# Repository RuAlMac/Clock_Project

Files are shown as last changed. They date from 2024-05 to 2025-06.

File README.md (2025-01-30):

<h1>RADM Clock Project</h1>

<p>Hello and welcome to the repository for my clock project! This project was inspired by redditor <a href="https://www.reddit.com/user/joshr120/"> u/joshr120</a>. See his post <a href="https://www.reddit.com/r/ArduinoProjects/comments/1caxkm6/my_clock_made_of_24_clocks_and_48_stepper_motors/">here</a>.</p>
<p>The various parts of this project are listed below.</p>

<p><h3>Custom Printed Circuit Boards (PCBs)</h3>
<ul>
  <li><strong>Individual Clock Board:</strong> 24 used, one for each analog clock (2 steppers, one for each hand)</li>
  <li><strong>Clock Cluster Board:</strong> 4 used, one for each segment (6 clocks)>/li>
  <li><strong>Power Routing Board:</strong> 1 used, includes fuses for distributing power safely to all steppers and microcontrollers</li>
  <li><strong>Small Parts Board:</strong> 50 used, two per clock for hall effect sensors for steppers, more for miscellaneous components</li>
</ul>
</p>

<p><h3>Code</h3>
<ul>
  <li>Individual Clock Board Code</li>
  <li>Main System Controller Code</li>
  <li>Regular Clock Cluster Board Code</li>
</ul>
</p>

<p><h3>3D-Printed Parts</h3>
<a href="https://cad.onshape.com/documents/1d75280899b064ab337b95c3/w/e03d29798e6817c57c79d56d/e/417be124aab67788fec76c11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">This Onshape workspace</a> contains all the parts I designed for this project, and also includes the assembly models for the entire project.
</p>

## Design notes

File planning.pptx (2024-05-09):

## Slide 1

Components for clock cluster board:
- IR Receiver (not all will have)
- RTC module (not all will have)
- 7-seg display
- 8 each GND, 5V, SDA, SCL
Pins on clock cluster board:
- Pins 2-4: Shift Register control (for 7seg display)
- Pin 5: DP control (for 7seg display)
- Pin 6: IR Receiver module data pin
- [RTC module uses I2C communication w/ Arduino]

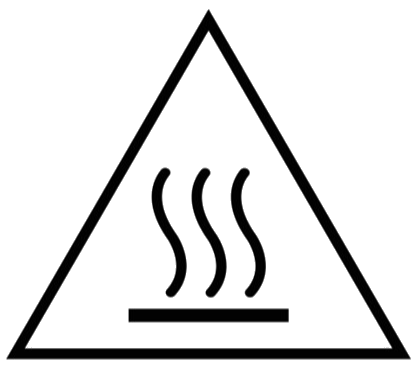
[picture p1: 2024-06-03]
PCBs/Power Routing Board/hot surface symbol.png

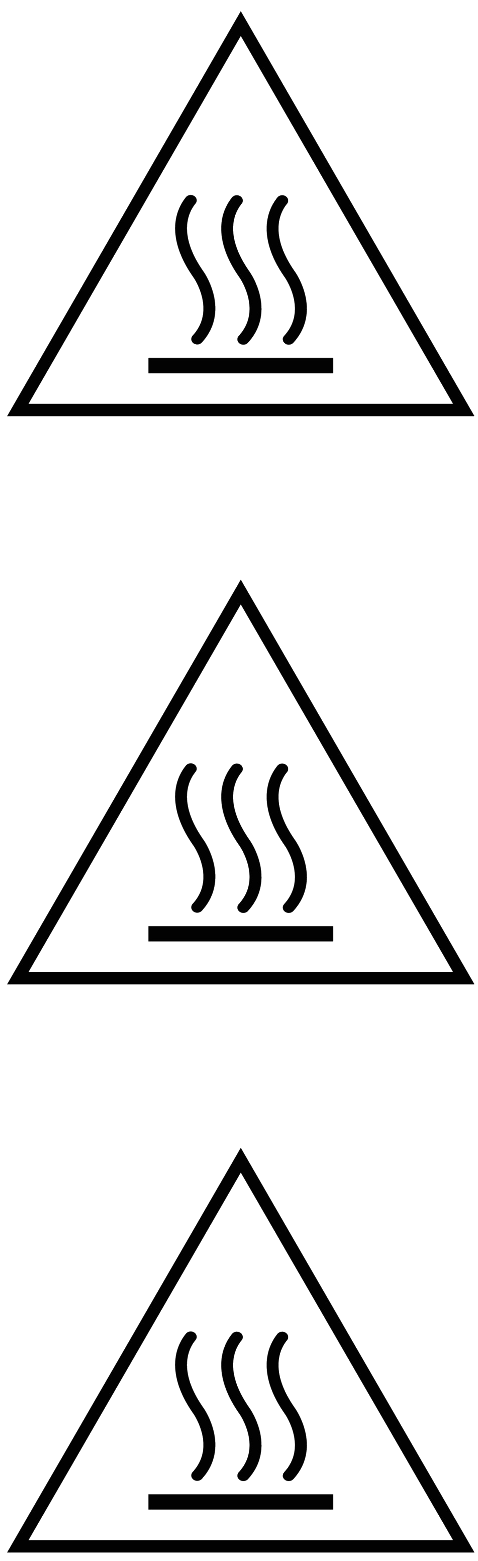
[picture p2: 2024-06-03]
PCBs/Power Routing Board/hot surface symbol x3.png

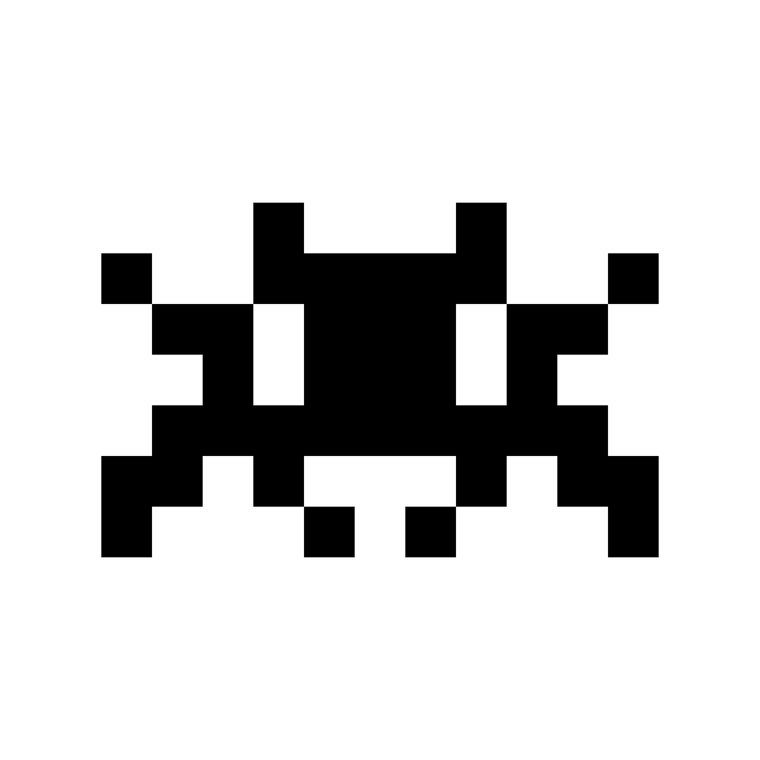
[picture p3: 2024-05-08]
PCBs/Single Clock Board/sprite.png

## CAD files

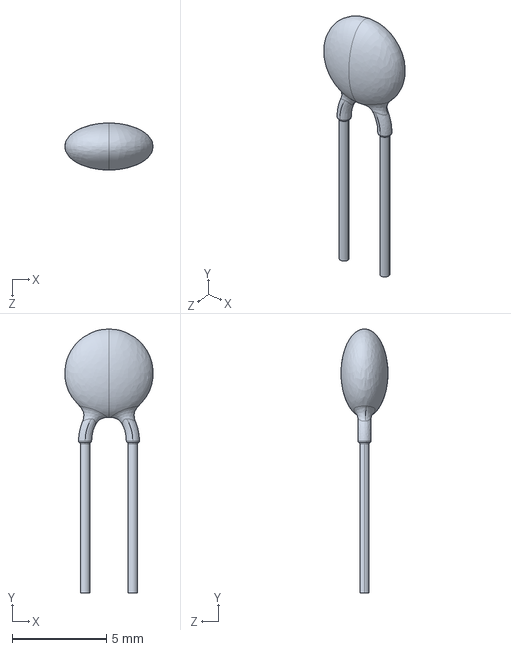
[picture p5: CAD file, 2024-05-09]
PCBs/3D Models/10pF Ceramic Disc 2.STEP
4.70 x 14.0 x 2.50 mm

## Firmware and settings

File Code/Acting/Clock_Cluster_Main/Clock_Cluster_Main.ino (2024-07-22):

/* *****Clock Cluster Main Board*****
    Peripherals:
        RTC Module
        Relay
        Shift Register for 7-Seg Display
        I2C LCD Display (16x2)
        I2C Bus for communication w/ Individual Clock Boards, other Clock Cluster Boards
*/

/*  IR Remote Used
   [1]   [2]   [3]    //numerals for setting time
   [4]   [5]   [6]
   [7]   [8]   [9]
   [*]   [0]   [#]    //[*]: toggle lighting, [#]: enter/exit clock setting (handled by board 51)
         [W]          //[W]: switch between analog mode and digital mode
   [A]   [=]   [D]    //[A]: select segment to the left, [D]: select segment to the right; [A] and [D] used for setting clock time only
         [S]          //[S]: freeze/unfreeze clock
*/

//**************UNIQUE SETTINGS FOR THIS BOARD**************
#define boardAddress    52    //address in decimal
#define initDelay       5     //time in seconds given to Individual Clock Boards to home steppers before status check
#define maxInitCnt      2     //how many times initialization can be attempted before fatal error #01
#define clockCheckDelay 450   //time in milliseconds between RTC checks, should be less than 1 second for optimal operation
#define irCheckDelay    20    //time in milliseconds that system rests before checking if the IR sensor has detected a signal
#define irDebounceDelay 800  //debounce time for IR signal inputs
#define overrideInitChk true  //for debugging purposes; if true, program ignores errors reported by Individual Clock Boards, SHOULD BE FALSE FOR NORMAL OPERATION
#define forceClockSet   false //for debugging purposes; program will only program RTC; this must be then set to false and reuploaded, see "Forced Time Set" section below
//**********************************************************

//################Forced Time Set################
int newSetTime[] = {2024, 7, 10, 4, 16, 5, 0}; //year, month, day, weekday#, hour, min, sec; Sunday is weekday #1; takes about 10 seconds to compile & upload
//###############################################

//I2C
#include <Wire.h>

//IR Remote
#include <IRremote.h>
#include <ir_Lego_PF_BitStreamEncoder.h>
const int irReceiver = 6;
IRrecv irrecv(irReceiver);
decode_results results;
unsigned long key_value = 0;
char receivedVal0;  //used to store a new input value
char receivedVal1 = '?';  //used to store the value input before the newest to prevent the same signal from triggering events repeatedly

//LCD Display
#include <LiquidCrystal_I2C.h>
LiquidCrystal_I2C lcd(0x27, 16, 2); //LCD address 0x27, dec 39

byte snowflake[] = {
  B10001,
  B01010,
  B00100,
  B11111,
  B00100,
  B01010,
  B10001,
  B00000
};

//RTC Module
#include <I2C_RTC.h>
static DS3231 RTC;
int year, month, day;
int weekday0, weekday1;
int hour0, hour1;
int minute0, minute1;
int second0, second1;

//Shift Register for 7-Seg Display
byte seven_seg_digits[10] = { B11111100,  // = 0
                              B01100000,  // = 1
                              B11011010,  // = 2
                              B11110010,  // = 3
                              B01100110,  // = 4
                              B10110110,  // = 5
                              B10111110,  // = 6
                              B11100000,  // = 7
                              B11111110,  // = 8
                              B11100110   // = 9
                            };

const int latchPin = 3;
const int clockPin = 4;
const int dataPin = 2;

//Relay
const int relayPin = 7;

//Buzzer
#include <TimerFreeTone.h>
int buzzerPin = 8;

//also using built-in LED

//Variables
volatile int clockStatus[24] = {};     //Array storing statuses of each Individual Clock Board
unsigned long time0 = 0;        //millis raw value
unsigned long time1 = 0;        //value for use in if statements
unsigned long time2 = 0;        //value for use in other features
unsigned long lastPressTime;    //stores the time when an IR button press was detected
int timeRemaining = 0;          //timer value
int initCount = 0;              //counts how many times initialization has been attempted
volatile int tempStorage = 0;   //used to ensure initCount variable is accurate b/c initCount variable is being a prissy litte bitch and I don't fucking know why it's so screwy fml
bool errorsPresent;             //used during system init, false only if all Individual Clock Boards report no errors at init
char irSignal;                  //stores the value of an IR signal received by the Clock_Cluster_IR board
bool keepLoop = false;          //for use in while loops that incorporate switch case operations, for simplicity
bool analogMode = false;        //indicates which display mode Individual Clock Boards should use; false=analog, true=digital
bool frozen = false;            //freezes or unfreezes clock updates

int selectedToEdit;             //used for time setting only; selectedToEdit=0 means hours are edited, selectedToEdit=1 means minutes are edited
int selectedOperation = 1;      //used to store which operation will be used in adjusting set time (0=subtraction, 1=addition)
char loadedVal[2] = {'?', '?'}; //used to store value for by how much the hour or minute value is to be modified in time setting mode
int loadedValInt;               //used to store value of loadedVal[] in an integer format for arithmatic purposes

int errorCode;                  //for use in reporting fatal errors
/* Error Codes
   01: Number of system initializations exceeds allowed (error likely due to stepper homing failure on 1+ Individual Clock Boards
   02: RTC not running (likely due to poor connection between I2C bus and RTC module, maybe RTC battery died)
   03: Unknown system mode (programming bug)
*/

int mode = 0;
/* Mode Variable
  -1: Error State (manual reset required)
   0: Initialization Delay (10 sec)
   1: Checking Clock Statuses
   2: Normal operation (includes switching between analog/digital and un/freezing clock)
   3: Setting time
*/


void setup() {
  //Serial monitor (debug)
  Serial.begin(9600);
  while (!Serial) {
    //do nothing
  }
  printSerial(1);

  //I2C Initialization
  Wire.begin(boardAddress);

  //IR Remote
  irrecv.enableIRIn();
  irrecv.blink13(false);

  //RTC Module
  RTC.begin();
  RTC.startClock();
  RTC.setHourMode(CLOCK_H24); //24Hr time instead of 12Hr time (CLOCK_H12)
  delay(10);
  printTimeSerial(getTime());

  //LCD Display
  lcd.init();  //initialize the lcd
  lcd.createChar(0, snowflake);
  lcd.backlight();  //open the backlight
  printLCD(0);

  //Shift Register
  pinMode(latchPin, OUTPUT);
  pinMode(clockPin, OUTPUT);
  pinMode(dataPin, OUTPUT);

  //Other Peripherals
  pinMode(LED_BUILTIN, OUTPUT);
  pinMode(relayPin, OUTPUT);

  //Checking overrides
  if (forceClockSet) {
    mode = 3;
  }

  delay(100);
}



void loop() {
  time0 = millis();

  switch (mode) {
    case -1:
      Serial.print("[+] Mode -1: Fatal Error, Manual Reset Required");
      printLCD(-1);
      while (1) {
        // do nothing
      }
      break;
    case 0:
      initCount = tempStorage;
      initCount = initCount + 1;
      tempStorage = initCount;
      delay(10);

      Serial.print("[+] Mode 0: Initialization Delay");
      Serial.print("\n\t[#] Init Count: ");
      Serial.print(initCount);
      Serial.print("\tmaxInitCnt: ");
      Serial.print(maxInitCnt);
      runCountdown(initDelay); //duration defined in board settings
      Serial.print("\n");
      mode = 1;
      break;

    case 1:
      Serial.print("[+] Mode 1: Checking Clock Statuses");
      getClockStatuses();

      Serial.print("\n\t[%] Errors present: ");
      initCount = tempStorage;

      if (overrideInitChk == true) { //debugging override accessible in settings; overrides checking all Individual Clock Boards for reported errors
        errorsPresent = false;
        Serial.print("[OVERRIDDEN] ");
      }

      switch (errorsPresent) {
        case true:
          Serial.print("True");
          if (initCount >= maxInitCnt) { //if initCnt has met or exceeded maxInitCnt
            Serial.print("\n\t[!] Fatal Error: initCnt >= maxInitCnt\n");
            Serial.print("\tError code: 1\n\n");
            errorCode = 1;
            delay(50);
            mode = -1;
          }
          else {
            Serial.print("\n\tinitCnt: ");
            Serial.print(initCount);
            Serial.print("\tmaxInitCnt: ");
            Serial.print(maxInitCnt);
            Serial.print("\tinitCnt < maxInitCnt, reattempting init\n\n");

            mode = 0;
          }
          break;
        case false:
          Serial.print("False\n\n");
          mode = 2;
          break;
      }
      break;

    case 2:
      Serial.print("[+] Mode 2: Normal Standby Mode (Timekeeping, Analog/Digital, Freeze/Unfreeze)");
      printLCD(1);
      keepLoop = true;

      for (int i = 1; i <= 5; i = i + 1) {
        printTimeLCD(i);
        delay(150);
      }

      while (keepLoop) {
        checkRTC();
        irSignal = decodeIR();

        if ( (irSignal != '?') && (irSignal != ' ') ) {
          switch (irSignal) { //checks if new IR signal has been received
            case '*': //toggle lighting
              Serial.print("\n\t[>] Mode 2, IR action '*': Toggle lighting");
              toggleRelay(); //toggleRelay() contains a call to playTone()
              break;
            case '#': //go to clock setting mode
              Serial.print("\n\t[>] Mode 2, IR action '#': Enter clock setting mode\n");
              mode = 3;
              playTone(500, 250);
              keepLoop = false;
              break;
            case 'w':  //toggle between digital and analog modes
              Serial.print("\n\t[>] Mode 2, IR action 'w': Toggle between Analog / Digital Setting");
              sendSysUpdate(1); //update type 1: toggle between digital & analog modes
              playTone(500, 500); //duration in ms, freq in Hz
              break;
            case 's': //freeze clock
              Serial.print("\n\t[>] Mode 2, IR action 's': Freeze clock");
              sendSysUpdate(2); //update type 2: toggle between frozen and unfrozen
              break;
          }
          irSignal = '?';
        }
      }
      break;

    case 3:
      Serial.print("[+] Mode 3: Time Setting");

      if (forceClockSet) { //Code here will only execute if the time set override in settings is true
        Serial.print(" [forceClockSet OVERRIDE ACTIVE]");
        printLCD(3);

        RTC.setYear(newSetTime[0]);
        RTC.setMonth(newSetTime[1]);
        RTC.setDay(newSetTime[2]);
        RTC.setWeek(newSetTime[3]);
        RTC.setHours(newSetTime[4]);
        RTC.setMinutes(newSetTime[5]);
        RTC.setSeconds(newSetTime[6]);

        if (getTime()) {
          Serial.print("\n");
          printTimeSerial(true);
          Serial.print("\t[!] Forced Time Set Successful; deactivate override and reprogram");
          while (1) {
            //wait for reprogram
          }
        }
      }

      //The below code will execute in normal operation
      Serial.print(" [Normal Operation]");

      printLCD(3);
      updateEditPlan();
      keepLoop = true;

      while (keepLoop) {
        irSignal = decodeIR();

        if ( (irSignal != '?') && (irSignal != ' ') ) {
          switch (irSignal) { //checks if new IR signal has been received
            case '*': //toggle lighting
              Serial.print("\n\t[>] Mode 3, IR action '*': Toggle lighting");
              toggleRelay(); //toggleRelay() contains a call to playTone()
              break;

            case '#': //exit clock setting mode
              mode = 2;
              playTone(500, 250); //duration in ms, freq in Hz
              Serial.print("\n\t[>] Mode 3, IR action '#': Exit clock setting mode\n");
              keepLoop = false;
              break;

            case 'w': //operation: add
              Serial.print("\n\t[&] Operation selected: addition");
              playTone(100, 250); //duration in ms, freq in Hz
              selectedOperation = 1;
              updateEditPlan();
              break;

            case 's': //operation: subtract
              Serial.print("\n\t[&] Operation selected: subtraction");
              playTone(100, 250); //duration in ms, freq in Hz
              selectedOperation = 0;
              updateEditPlan();
              break;

            case 'a': //choose to modify hour value
              Serial.print("\n\t[&] Hours selected to be modified");
              playTone(100, 250); //duration in ms, freq in Hz
              selectedToEdit = 0;
              updateEditPlan();
              break;

            case 'd': //choose to modify minute value
              Serial.print("\n\t[&] Minutes selected to be modified");
              playTone(100, 250); //duration in ms, freq in Hz
              selectedToEdit = 1;
              updateEditPlan();
              break;

            case '=': //confirm change to hour or minute value
              playTone(500, 250); //duration in ms, freq in Hz
              getTime();

              Serial.print("\n\t[!] Confirmed time change; input time change plan:");
              Serial.print("\n\t\t[*] Adjust ");

              //Step 1: Convert value in loadedVal[] array to an integer (stored in loadedValInt)
              loadedValInt = 0;

              if (loadedVal[0] != '?') {
                loadedValInt = (loadedVal[0] - '0') * 10;
              }

              if (loadedVal[1] != '?') {
                loadedValInt = loadedValInt + (loadedVal[1] - '0');
              }

              //Step 2: Make loadedValInt value negative if needed
              if (selectedOperation == 0) { //if subtraction selected as operator
                loadedValInt = loadedValInt * (-1);
              }

              //Step 3: Compute new hour or minute (depending on selectedToEdit variable)
              if (selectedToEdit == 0) { //hours
                Serial.print("<hour>");
                hour1 = hour0 + loadedValInt;
                checkIfValid(0);
              }

              if (selectedToEdit == 1) { //minutes
                Serial.print("<minute>");
                minute1 = minute0 + loadedValInt;
                checkIfValid(0);
              }

              if (loadedValInt > 0) {
                Serial.print("+");
              }

              Serial.print(" by <");
              Serial.print(loadedValInt);
              Serial.print(">");

              //Step 4: Update time
              RTC.setDay(day);
              RTC.setHours(hour1);
              RTC.setMinutes(minute1);

              Serial.print("\n\t\t[*] New date/time:");
              printTimeSerial(getTime());


              mode = 2;
              keepLoop = false;
              break;

            default:
              int z = irSignal - '0'; //converts value stored in irSignal to an int

              if ((z >= 0) && (z <= 9)) { //only executes code if an integer value of 0 <= x <= 9 is stored in z
                playTone(100, 250); //duration in ms, freq in Hz
                if ( (loadedVal[0] == '?') && (loadedVal[1] == '?') ) {   //loadedVal[] stores value as tens, ones
                  //loadedVal[0] still is '?'
                  loadedVal[1] = irSignal;
                  Serial.print("\n\t[&] Current value set to: [0");
                  Serial.print(z);
                  Serial.print("]");
                }
                else if ( (loadedVal[0] == '?') && (loadedVal[1] != '?') ) {
                  loadedVal[0] = irSignal;
                  Serial.print("\n\t[&] Current value set to: [");
                  Serial.print(z);
                  Serial.print(loadedVal[1] - '0');
                  Serial.print("]");
                }
                else if ( (loadedVal[0] != '?') && (loadedVal[1] != '?') ) {
                  loadedVal[1] = '?';
                  loadedVal[0] = '?';
                  Serial.print("\n\t[&] Current value reset");
                }
                updateEditPlan();
              }
              break;

          }
          irSignal = '?';
        }
      }

      break;

    default:
      Serial.print("\n\t[!] Fatal Error: Unknown system mode\tInput Mode: [");
      Serial.print(mode);
      Serial.print("]");
      Serial.print("\n\tError code: 3\n\n");
      errorCode = 3;
      mode = -1;
      break;
  }
}

void runCountdown(int duration) {
  timeRemaining = duration;
  time1 = time0 + (duration * 1000);
  time2 = time0 + 1000;

  lcdShowTimer(1); //prints the brackets
  Serial.print("\n\t[*] Countdown Started\n");
  Serial.print("\t[*] Duration: ");
  Serial.print(duration);
  Serial.print("\t\t");
  Serial.print("Start Time (time0) = ");
  Serial.print(time0);
  Serial.print("\t");
  Serial.print("End Time (time1) = ");
  Serial.print(time1);

  Serial.print("\n\t[*] Time Remaining: ");

  while (time1 >= time0) {
    time0 = millis();

    if (time0 >= time2) {
      timeRemaining = timeRemaining - 1;
      Serial.print(timeRemaining);
      Serial.print("  ");
      time2 = time0 + 1000;
      lcdShowTimer(2); //updates timeRemaining on the LCD
    }
  }
  Serial.print("Complete\n");
}

/*void shortCountdown(int duration) {
  timeRemaining = duration;
  time1 = time0 + (duration * 1000);
  time2 = time0 + 1000;

  Serial.print("\n\t[*] Short Countdown");
  Serial.print("\t[*] Duration: ");
  Serial.print(duration);
  Serial.print("\t\t");
  Serial.print("Start Time (time0) = ");
  Serial.print(time0);
  Serial.print("\t");
  Serial.print("End Time (time1) = ");
  Serial.print(time1);

  Serial.print("\t[*] Time Remaining: ");

  while (time1 >= time0) {
    time0 = millis();

    if (time0 >= time2) {
      timeRemaining = timeRemaining - 1;
      Serial.print(timeRemaining);
      Serial.print("  ");
      time2 = time0 + 1000;
    }
  }
  Serial.print("\tComplete\n");
  }*/

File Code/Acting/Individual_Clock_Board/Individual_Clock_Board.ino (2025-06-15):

/* *****Individual Clock Board*****
    Peripherals:
        Hall Effect Sensors (2x) INPUT
        Stepper Controllers (2x) OUTPUT
        I2C Bus for communication w/ Clock Cluster boards

    Reference document below for appropriate I2C device addresses and communication schemes:
      https://docs.google.com/document/d/1MbWG_syWLBZlh941dtcajAVfe2LQ0b-RFf0K8S4ZPrs/edit?usp=sharing

    Reference link below for 28BYJ-48 Stepper tutorial
      https://github.com/NikodemBartnik/ArduinoTutorials/tree/master
*/

/*  Orientation Chart: (in current code, this is calculated automatically from boardAddress)
        [0   1] <--Clock segment
        [2   3]
        [4   5]
*/

//**************UNIQUE SETTINGS FOR EACH BOARD**************
#define boardAddress     34   //address in decimal
//**********************************************************

//~~~~~~~~~~~~~~~~~~Constants~~~~~~~~~~~~~~~~~~
#define stepsInRev       2048 //number of steps in a full rotation of 28BYJ-48 Steppers
//~~~~~~~~~~~~~~~~~~~~~~~~~~~~~~~~~~~~~~~~~~~~~

//I2C
#include <Wire.h>
volatile byte i2c_message = 1;  //not sure if I'm going to keep this variable
char receivedMessage[7] = {'5', '_', '5', '5', '5', '5'}; //includes extra space for '\0' str terminator

//Board Position
char seg; //stores which segment this board operates in
int pos;  //stores this board's position in its segment

//System Operation
int receivedDigit;              //stores the value received from the receiveEvent I2C function
bool newTimeValue = false;      //set to true if the receiveEvent I2C function receives a new valid time value
bool analogMode = false;        //indicates which display mode Individual Clock Boards should use; false=analog, true=digital
bool frozen = false;            //indicates clock freeze status; frozen=true, freeze; frozen=false, unfreeze

bool homingComplete = false;    //used to track if homing sequence was completed successfully

int step_nums[2] = {0, 0};      //NOT A COUNT OF TOTAL STEPPER STEPS! Used to count in fours to determine next appropriate step type
int step_counts[2] = {0, 0};    //Used to track position of steppers, should be reset to 0 during homing sequence

int newAngle[2];                //updated by getNewAngle function
int currentPos[2] = {0,0};      //stores where steppers currently are
int newPos[2] = {0,0};            //stores where steppers must be moved to

//These capitalized variables are used in the stepOnce function
int STEP_NUMBER;
int STEPPER_PIN[4] = {0, 0, 0, 0};

//Pin Assignments
int step_1_poles[] = {2, 3, 4, 5}; //pins for poles for Stepper 1
int step_2_poles[] = {6, 7, 8, 9}; //pins for poles for Stepper 2
int hall_sensors[] = {10, 11};     //pins for Hall Effect Sensors: 1, 2

void setup() {
  //Serial monitor initialization
  Serial.begin(9600);
  while (!Serial) {
    //do nothing
  }
  Serial.print("\n\n\n\n\n\n");
  Serial.print("**********Initializing Single Clock Board**********\n");

  //I2C Initialization
  Wire.begin(boardAddress); //slave address 1
  Wire.onReceive(receiveEvent);
  Wire.onRequest(requestEvent);

  //pinMode initialization
  pinMode(step_1_poles[0], OUTPUT);
  pinMode(step_1_poles[1], OUTPUT);
  pinMode(step_1_poles[2], OUTPUT);
  pinMode(step_1_poles[3], OUTPUT);

  pinMode(step_2_poles[0], OUTPUT);
  pinMode(step_2_poles[1], OUTPUT);
  pinMode(step_2_poles[2], OUTPUT);
  pinMode(step_2_poles[3], OUTPUT);

  pinMode(LED_BUILTIN, OUTPUT);

  pinMode(hall_sensors[0], INPUT);
  pinMode(hall_sensors[1], INPUT);

  //Determine board segment and position
  getBoardLocation();

  //Stepper homing
  homeSteppers();
}

void loop() {

  if (newTimeValue == true) { //if a new valid time value is received

    if (frozen == false) {

      switch (analogMode) {
        case false: //DIGITAL display mode
          moveSteppers_digital(receivedDigit, 1); //arguments: digit, movementScheme
          break;
        case true:  //ANALOG display mode
          break;
      }
    } //(frozen if statement)

    newTimeValue = false; //frozen or unfrozen, program still sets this to false after newTimeValue received
  } //(newTimeValue if statement)

}

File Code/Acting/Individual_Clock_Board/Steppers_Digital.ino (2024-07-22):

//NOTE: all this code is only used when clock is in DIGITAL display mode; ANALOG display mode code handled elsewhere

/*  Orientation Chart:
        [0   1] <--Clock segment
        [2   3]
        [4   5]
*/

/*       0     <-- Angles
          8
    275     15
      38
        30
*/

void moveSteppers_digital(int digit, int movementScheme) {

  //*****Declaring local variables for this function*****
  float stepsInRev_float = static_cast<float>(stepsInRev); //stores stepsInRev as a float value
  int toMove[2] = {0, 0};                                  //stores the number of steps (+) or (-) that either stepper will need to move
  bool stepDir[2];                                         //direction: true=clockwise, false=counterclockwise
  int mx, hx;                                              //temporary index variables, count number of remaining steps for either stepper
  int dx[4] = {0, 0, 0, 0};                                //temporary index variable, stores number of steps needed to move stepper clockwise, or counter-clockwise (compares to determine direction)

  //*****Determining step direction and step distance for each stepper*****
  getNewAngle(digit);

  Serial.print("\n\n\t[!] moveSteppers_digital function called");
  Serial.print("\n\t\t[*] New digit: <");
  Serial.print(digit);
  Serial.print(">");

  for (int i = 0; i < 2; i = i + 1) {                   //~~~~~~~~~~~~~~~~~~~~~~~Code below will be executed twice (once for each stepper)

    Serial.print("\n\t\t[*] ");

    if (i == 0) {
      Serial.print("Minute");
    }
    else {
      Serial.print("Hour");
    }

    Serial.print(" Stepper");

    //Determine new step position using floating point math
    newPos[i] = static_cast<float>(newAngle[i]);        //convert int to float
    newPos[i] = ( (newPos[i] / 60.0) * stepsInRev_float);  //float-point arithmatic, converts given base-60 angle to a usable step value
    newPos[i] = static_cast<int>(newPos[i]);          //convert float to int, truncates decimal part of answer

    Serial.print("\n\t\t\t\tnewAngle: ");
    Serial.print(newAngle[i]);
    Serial.print("\n\t\t\t\tcurrentPos[i]: ");
    Serial.print(currentPos[i]);
    Serial.print("\n\t\t\t\tnewPos[i]: ");
    Serial.print(newPos[i]);

    dx[0] = currentPos[i];      //store current step pos in dx[0]
    dx[1] = newPos[i];          //store new step pos in dx[1]
    dx[2] = 0;                  //stores the number of steps needed for stepper to move to newPos CLOCKWISE
    dx[3] = 0;                  //stores the number of steps needed for stepper to move to newPos COUNTERCLOCKWISE

    //CLOCKWISE (# of steps needed to reach newPos CW)
    while (dx[0] != dx[1]) {
      if (dx[1] == 2048) {  //if dx[1] is in overflow
        dx[1] = 0; //reset to 0
        Serial.print("\n\t\t\t\tClockwise overflow, reset to 0");
      }
      else { //if dx[1] is not in overflow
        dx[1] = dx[1] + 1;
        dx[3] = dx[3] + 1;
      }
    }

    //Reset between calculations
    dx[0] = currentPos[i];      //store current step pos in dx[0]
    dx[1] = newPos[i];          //store new step pos in dx[1]
    //dx[3] = 0;                  //stores the number of steps needed for stepper to move to newPos COUNTERCLOCKWISE

    //COUNTERCLOCKWISE (# of steps needed to reach newPos CCW)
    while (dx[0] != dx[1]) {
      if (dx[1] == 0) {  //if dx[1] is in overflow
        dx[1] = 2048; //reset to 0
        Serial.print("\n\t\t\t\tCounterclockwise overflow, reset to 2048");
      }
      else { //if dx[1] is not in overflow
        dx[1] = dx[1] - 1;
        dx[2] = dx[2] + 1;
      }
    }

    Serial.print("\n\t\t\t\tdx[2]: ");
    Serial.print(dx[2]);
    Serial.print("  dx[3]: ");
    Serial.print(dx[3]);

    Serial.print("\n\t\t\t\tDirection: ");

    //Compare distances
    if (dx[2] < dx[3]) {
      stepDir[i] = true; //move clockwise
      toMove[i] = dx[2];
      Serial.print("Clockwise (dx[2] < dx[3]");
    }
    else if (dx[3] < dx[2]) {
      stepDir[i] = false; //move counterclockwise
      toMove[i] = dx[3];
      Serial.print("Counterclockwise (dx[3] < dx[2]");
    }
    else {
      stepDir[i] = true; //move clockwise
      toMove[i] = dx[2];
      Serial.print("Clockwise (dx[2] == dx[3]");
    }

    //Update current position
    currentPos[i] = newPos[i];

  } //~~~~~~~~~~~~~~~~~~~~~~~~~~end of for loop

  //Updating movement indexes
  mx = (toMove[0]);
  hx = (toMove[1]);

  moveSteppers(mx, hx, stepDir[0], stepDir[1], movementScheme); //arguments: mx, hx, stepDirM, stepDirH, movementScheme
}

void getNewAngle(int digit) { //this function returns where a stepper should point in terms of minute poisitions (angles, but in base-60)

  switch (digit) {

    case 0:
      switch (pos) {
        case 0:
          newAngle[0] = 30; //minutes
          newAngle[1] = 15; //hours
          break;
        case 1:
          newAngle[0] = 45; //minutes
          newAngle[1] = 30; //hours
          break;
        case 2:
          newAngle[0] = 30; //minutes
          newAngle[1] = 0; //hours
          break;
        case 3:
          newAngle[0] = 0; //minutes
          newAngle[1] = 30; //hours
          break;
        case 4:
          newAngle[0] = 15; //minutes
          newAngle[1] = 0; //hours
          break;
        case 5:
          newAngle[0] = 0; //minutes
          newAngle[1] = 45; //hours
          break;
      }
      break;

    case 1:
      switch (pos) {
        case 0:
          newAngle[0] = 38; //minutes
          newAngle[1] = 38; //hours
          break;
        case 1:
          newAngle[0] = 30; //minutes
          newAngle[1] = 30; //hours
          break;
        case 2:
          newAngle[0] = 38; //minutes
          newAngle[1] = 38; //hours
          break;
        case 3:
          newAngle[0] = 0; //minutes
          newAngle[1] = 30; //hours
          break;
        case 4:
          newAngle[0] = 38; //minutes
          newAngle[1] = 38; //hours
          break;
        case 5:
          newAngle[0] = 0; //minutes
          newAngle[1] = 0; //hours
          break;
      }
      break;

    case 2:
      switch (pos) {
        case 0:
          newAngle[0] = 15; //minutes
          newAngle[1] = 15; //hours
          break;
        case 1:
          newAngle[0] = 30; //minutes
          newAngle[1] = 45; //hours
          break;
        case 2:
          newAngle[0] = 30; //minutes
          newAngle[1] = 15; //hours
          break;
        case 3:
          newAngle[0] = 45; //minutes
          newAngle[1] = 0; //hours
          break;
        case 4:
          newAngle[0] = 15; //minutes
          newAngle[1] = 0; //hours
          break;
        case 5:
          newAngle[0] = 45; //minutes
          newAngle[1] = 45; //hours
          break;
      }
      break;
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

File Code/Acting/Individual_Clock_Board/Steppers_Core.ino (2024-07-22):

void homeSteppers() {
  Serial.print("\n\t[!] Running stepper homing sequence");

  Serial.print("\n\t\t[*] Homing Stepper 1 (minute stepper)");
  while (digitalRead(hall_sensors[0]) != LOW) { //hall effect sensors return 'low' if there IS a magnet nearby
    stepOnce(false, 'm', 2);
  }
  step_nums[0] = 0;     //Used in stepOnce function
  step_counts[0] = 0;   //Used in stepOnce function
  currentPos[0] = 0;    //Used in digital display mode functions
  minPosition[0] = 0;   //Used in analog display mode functions
  quitMotor(true, 'm');
  Serial.print("\n\t\t[*] Stepper 1 homed.");

  Serial.print("\n\t\t[*] Homing Stepper 2 (hour stepper)");
  while (digitalRead(hall_sensors[1]) != LOW) {
    stepOnce(false, 'h', 2);
  }
  step_nums[1] = 0;     //Used in stepOnce function
  step_counts[1] = 0;   //Used in stepOnce function
  currentPos[1] = 0;    //Used in digital display mode functions
  hourPosition[0] = 0;  //Used in analog display mode functions
  quitMotor(true, 'h');
  Serial.print("\n\t\t[*] Stepper 2 homed.");

  homingComplete = true;
}

void quitMotor(bool flash, char motor) { //should be called when a certain motor is done being used
  switch (motor) {
    case 'm':
      digitalWrite(step_1_poles[0], LOW);
      digitalWrite(step_1_poles[1], LOW);
      digitalWrite(step_1_poles[2], LOW);
      digitalWrite(step_1_poles[3], LOW);

      if (flash == true) {
        digitalWrite(step_1_poles[2], HIGH);
        delay(500);
        digitalWrite(step_1_poles[2], LOW);
      }
      break;
    case 'h':
      digitalWrite(step_2_poles[0], LOW);
      digitalWrite(step_2_poles[1], LOW);
      digitalWrite(step_2_poles[2], LOW);
      digitalWrite(step_2_poles[3], LOW);

      if (flash == true) {
        digitalWrite(step_2_poles[2], HIGH);
        delay(500);
        digitalWrite(step_2_poles[2], LOW);
      }
      break;
  }
}

void moveSteppers(int mx, int hx, int stepDirM, int stepDirH, int movementScheme) { //used for both Steppers_Analog and Steppers_Digital functions
  Serial.print("\n\t\t[*] Movement Scheme: ");
  //*****Movement schemes*****
  switch (movementScheme) {
    case 1: //Moving synchronously (minute steps once, then hour, then min, etc.)
      Serial.print("Synchronous");
      Serial.print("\n\t\t\tmx = ");
      Serial.print(mx);
      Serial.print("\thx = ");
      Serial.print(hx);

      while ((mx != 0) || (hx != 0)) { //while steps remain for either minute or hour stepper

        if (mx != 0) { //if steps remain for minute stepper
          stepOnce(!stepDirM, 'm', 2); //arguments: direction, stepper, delay in ms; Note that the stepDir for the minutes stepper is noted b/c min step is rotated 180 deg to hour step in the mech baseplate
          mx = mx - 1;
        }

        if (hx != 0) { //if steps remain for hour stepper
          stepOnce(stepDirH, 'h', 2);
          hx = hx - 1;
        }
      }
      break;

    case 2: //Moving asychnronously (minute does all its stepping, then hour does its stepping)
      Serial.print("(Asynchronous Movement)");
      while (mx != 0) {
        stepOnce(stepDirM, 'm', 2); //arguments: direction, stepper, delay in ms
        mx = mx - 1;
      }
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

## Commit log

2024-05-08 05/07 Update
    [Single Clock Board.PrjPcb, main.PcbDoc, main.SchDoc]
2024-05-09 5/09 update
    [10pF Ceramic Disc 2.STEP, Clock Cluster Board.PrjPcb, main.SchDoc]
2024-05-10 05/10 update
    [Clock Cluster Board.PrjPcb, main.SchDoc]
2024-05-13 05/12 update
    [Small Device Board.PrjPcb, main.PcbDoc, main.SchDoc]
2024-05-15 05/15 update
    [main.SchDoc]
2024-05-20 05/20 update
    [main.SchDoc]
2024-06-03 06/02 update
    [Power Routing Board.PrjPcb, Small Device Board.PrjPcb, main.PcbDoc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]
2024-06-26 06/26 Update
    [Clock Cluster Board.PrjPcb, Power Routing Board.PrjPcb, Single Clock Board.PrjPcb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]
2024-07-17 07/17/2024 Update
    So much has changed it's wild
    [main.PcbDoc, main.SchDoc]
2024-07-22 07/22 Update (1)
    Before I delete and redo all the code I did for steppers_digital fml times 1000
    [main.SchDoc]
2024-07-22 07/22 Code Update
    Code is all tentatively complete, except for Clock Cluster boards (just need to do the segment shift register thingy) YIPPEE
2024-07-23 07/23 Update
    "Finished" coding for the most part (except for regular clock cluster boards, but those will be pretty straightforward. Also generated zipped GerberX2 files for PCB assembly.
    [Clock Cluster Board.PrjPcb, Power Routing Board.PrjPcb, Single Clock Board.PrjPcb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]
2024-07-30 07/30 Update
    [Clock Cluster Board.PrjPcb, main.PcbDoc, main.SchDoc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]
2025-04-28 04/28
    I don't think there were any changes, I think I just opened/closed these files, maybe moved something by accident and undid it, just pushing it to be save.
    [Single Clock Board.PrjPcb]
